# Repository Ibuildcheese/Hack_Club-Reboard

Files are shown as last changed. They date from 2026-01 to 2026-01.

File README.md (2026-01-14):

# The ReBoard
This is an 87 key custom ANSI mechanical keyboard with a Raspberry Pi Pico microcontroller using QMK Software to program the Pico. All keys in the firmware are 100% ANSI and I am using Cherry MX Blue switches.

### Why/how i made this
Firstly, i want to say that this will be the first PCB that i have ever made and it was all because i thought making a new keyboard would be easier than cleaning my old one. My dell keyboard, sk-8125, my dad bought before i was born, and it was discontinued 10 years ago, so i comitted myself to making a keyboard better than something from that time period by myself. Firstly, I looked up a bunch of tutorial videos but since they didn't help me at all i decided to just get started and go from there however, there was a lot of time in between from waiting on a friend to answer a question i had to having to completely scrapping my initial 100% keyboard i had in mind because of some fatal errors i made during the schematic. With the amount of issues and redos i encountered, i never would have thought i'd finish in time, let alone ~15 days before the deadline. Even though all this inexperience did come at a cost (i.e. spending 3 whole days to find a 3d-model of a cherry MX switch) i still cant thank Hack Club enough for giving me the opportunity to actually get started making amazing projects like these and being able to learn and problem solve along the way.

### Completion Chart

| Name | Status | Extra |
| :-: | :-: | :-: |
| PCB | Designed and order ready |  |
| PCB-Parts | Chosen, order ready |  |
| Case | Designed, not yet printed |  |
| Firmware | Configured, not yet tested on hardware |  |

___

## Screenshots of Design: 
| PCB - Front - Rendered | PCB - Back Rendered |
| :-: | :-: |
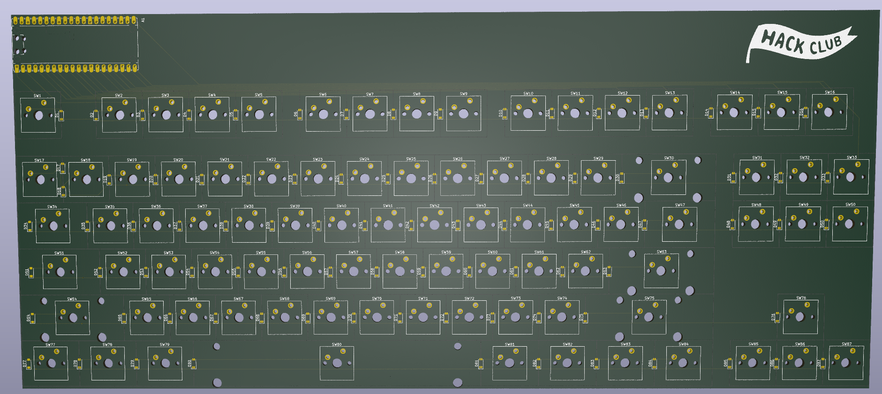
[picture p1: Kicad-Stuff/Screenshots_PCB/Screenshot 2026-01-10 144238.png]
PCB-Front-Rendered
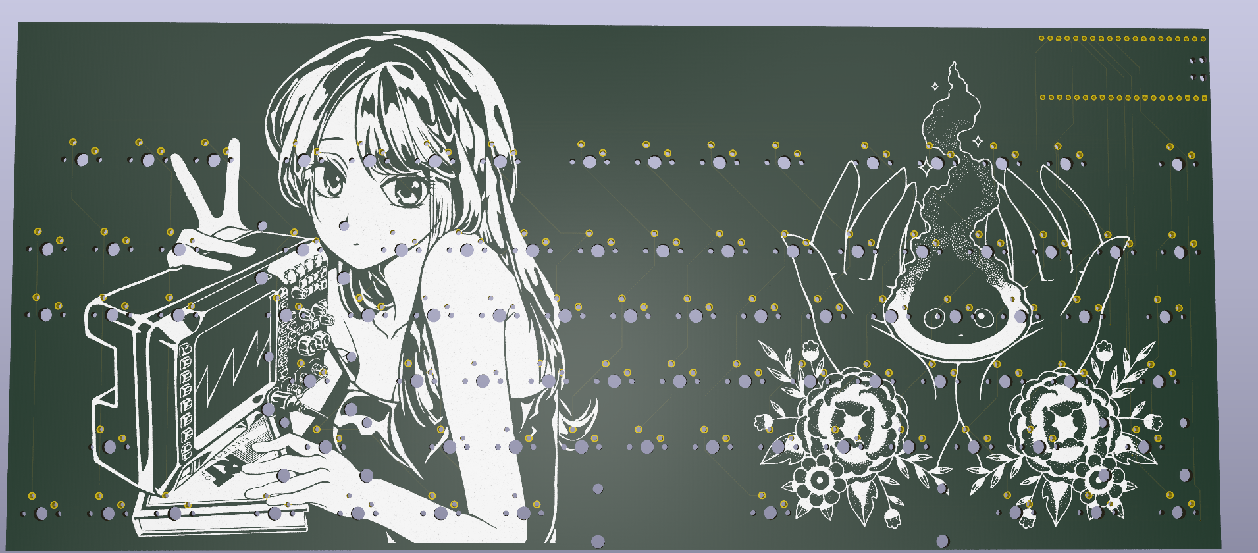
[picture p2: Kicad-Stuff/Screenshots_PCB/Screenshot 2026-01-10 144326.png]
PCB-Back-Rendered
|  |  |
| PCB - Editor - No-Silk | PCB - Editor - Silk |
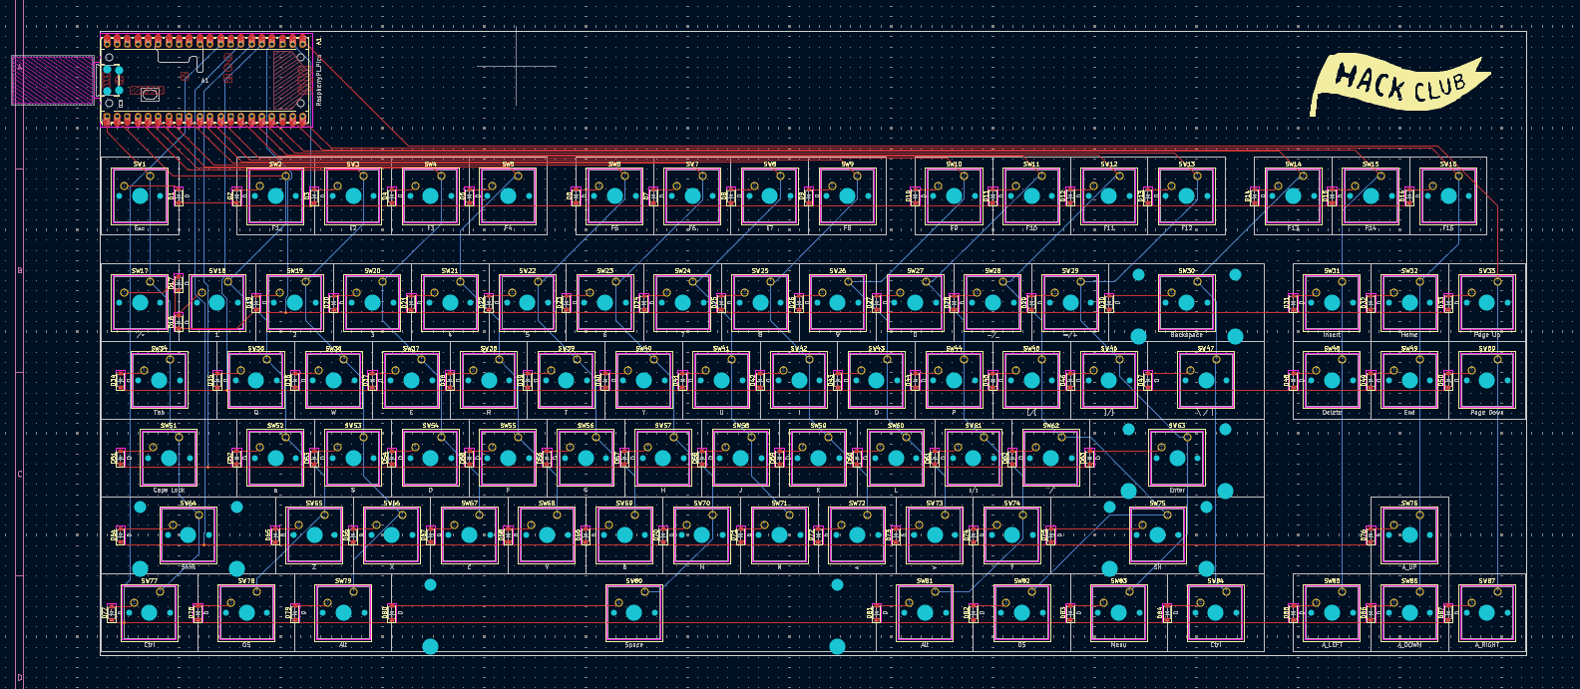
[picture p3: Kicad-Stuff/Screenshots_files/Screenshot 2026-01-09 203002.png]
PCB-Editor-No-Silk
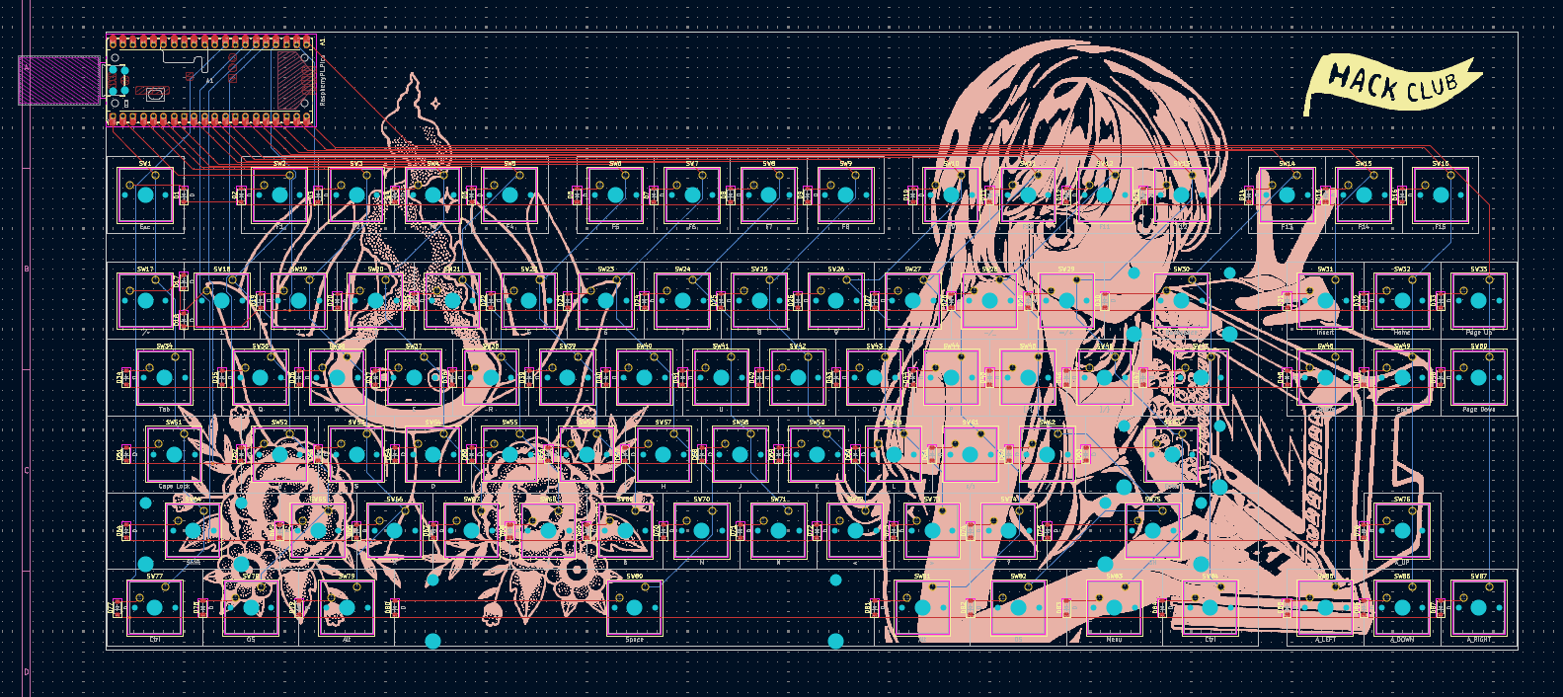
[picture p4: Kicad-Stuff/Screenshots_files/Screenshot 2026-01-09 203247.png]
PCB-Editor-Silk
|  |  |

| Schematic | 
| - |
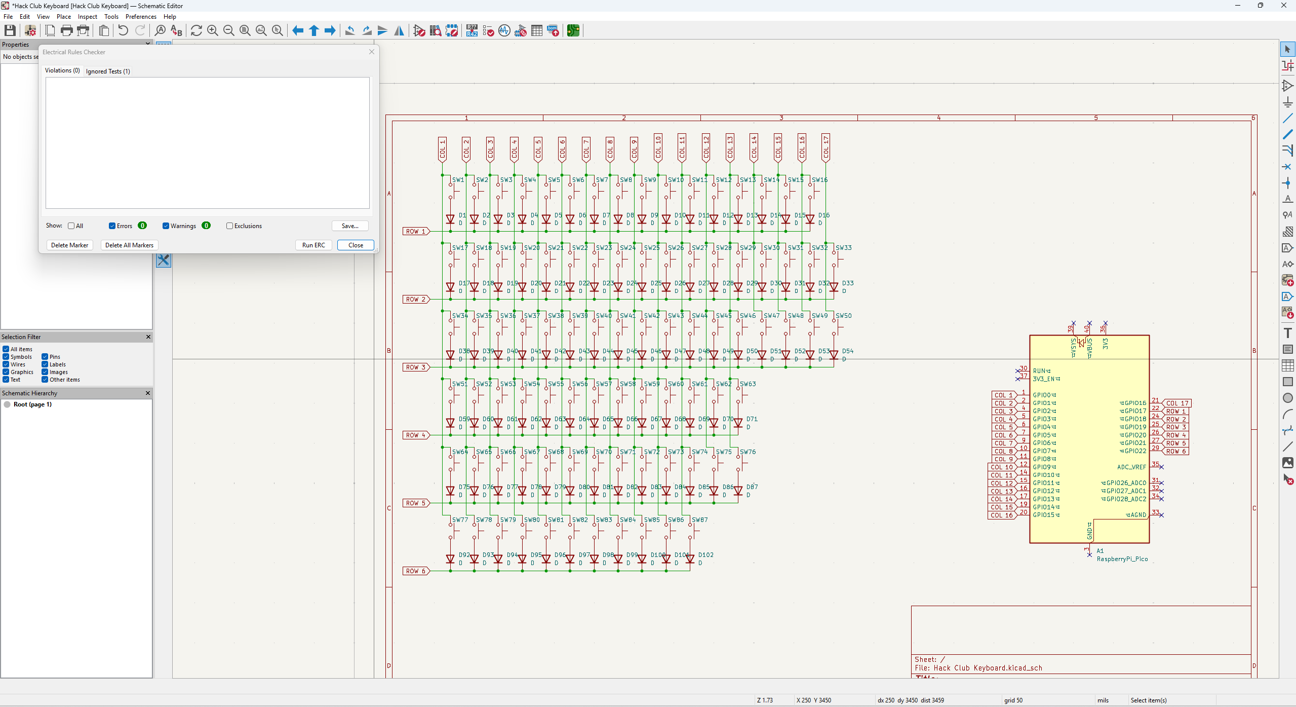
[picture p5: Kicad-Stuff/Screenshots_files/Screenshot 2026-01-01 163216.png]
Schematic-Img
|  |

| CAD - Render - Main |
| - |
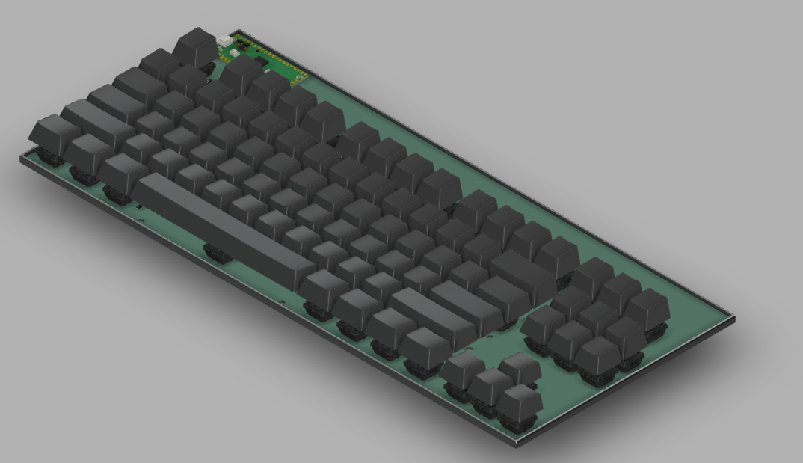
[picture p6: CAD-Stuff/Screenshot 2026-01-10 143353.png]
CAD-Render-Main
|  |

| CAD - Render - Top | Cad - Render - Bottom |
| - | - |
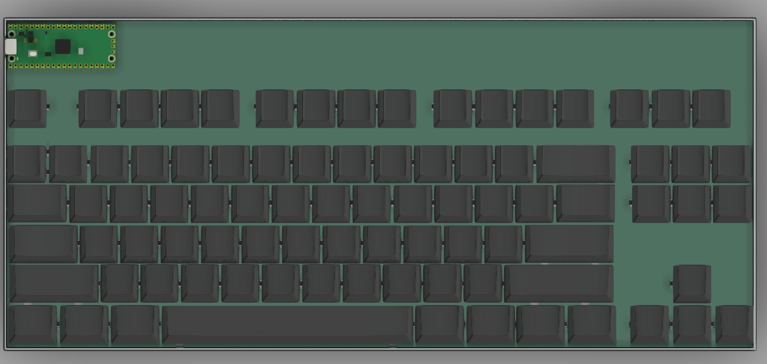
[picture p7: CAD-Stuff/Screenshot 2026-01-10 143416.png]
CAD-Render-Top
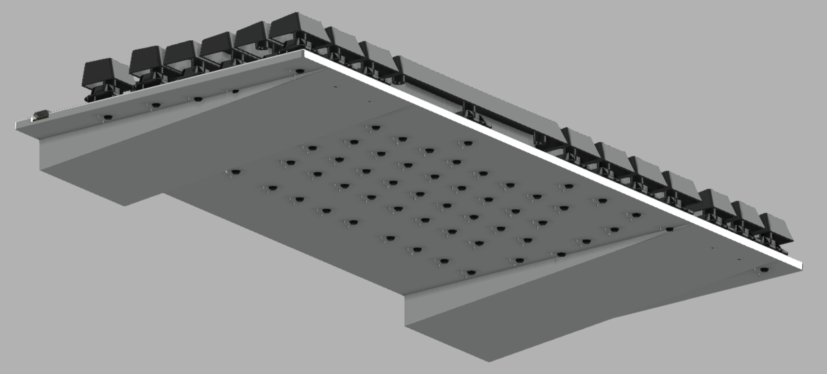
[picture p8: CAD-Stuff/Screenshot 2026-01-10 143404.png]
CAD-Render-Bottom
|  |  |

___

## BOM

| Amt | Name | Price | Link | Extra |
| - | - | - | - | - |
| x90 | Cherry MX Blue Switches | $34.50 | [Link](https://www.aliexpress.us/item/3256806124797516.html?) | Color: Blue, 90pcs |
| x98 | Cherry Profile Keycaps | $11.72 | [Link](https://www.aliexpress.us/item/3256808041449227.html?) | color: beige |
| x5 | Stabilizers | $0.99 | [Link](https://www.aliexpress.us/item/2251832533420646.html?) | 1x6.25 (6u or 7u) + 4x2u |
| x100 | Diodes | $1.30 | [Link](https://www.aliexpress.us/item/3256807350544438.html?) | 100pc option |
| 1x | PCB | $21.35 | [Link](https://jlcpcb.com) | --- |
| 1x | 3d Printed Case | --- | --- | I will print it myself |
| 1x | Raspberry Pi Pico | $3.75 | [Link](https://www.aliexpress.us/item/3256806652932348.html?) | --- |
| --- | Total | $73.61 | --- | --- |

| BOM - Screenshot - PCB |
| :-: |
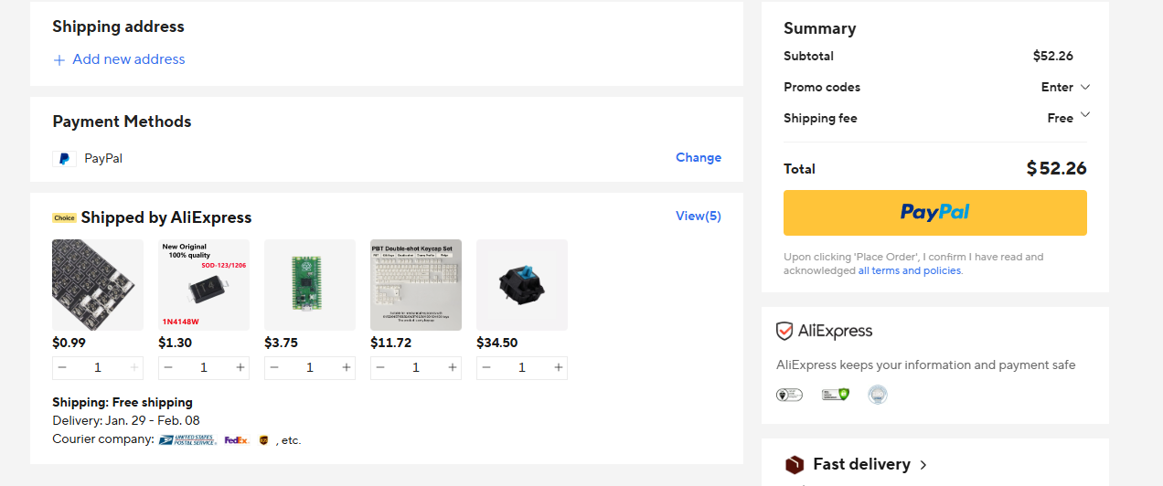
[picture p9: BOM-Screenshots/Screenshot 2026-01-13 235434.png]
PCB-BOM-SS
|  |
| BOM - Screenshot - AliExpress |
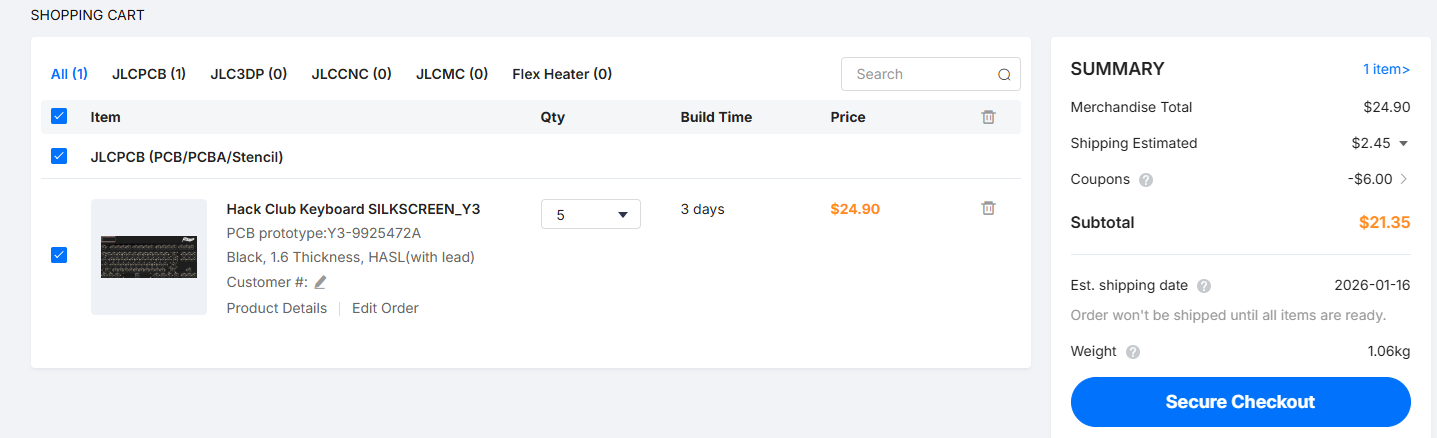
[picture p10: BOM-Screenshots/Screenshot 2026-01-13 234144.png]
AliExpress-BOM-SS
|  |

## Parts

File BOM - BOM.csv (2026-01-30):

Amount | Item | Price | Link | Misc.
x90 | Cherry MX Blue Switches | $34.50 | https://www.aliexpress.us/item/3256806124797516.html? | Color: Blue, 90pcs
x98 | Cherry Profile Keycaps | $11.72 | https://www.aliexpress.us/item/3256808041449227.html? | color: beige
x5 | Stabilizers | $0.99 | https://www.aliexpress.us/item/2251832533420646.html? | 1x6.25 (6u or 7u) + 4x2u
x100 | Diodes | $1.30 | https://www.aliexpress.us/item/3256807350544438.html? | 100pc option
x1 | PCB | $21.35 | https://jlcpcb.com
x1 | 3d Printed Case
x1 | Raspberry Pi Pico | $3.75 | https://www.aliexpress.us/item/3256806652932348.html? | I will print it myself
 | Total | $73.61

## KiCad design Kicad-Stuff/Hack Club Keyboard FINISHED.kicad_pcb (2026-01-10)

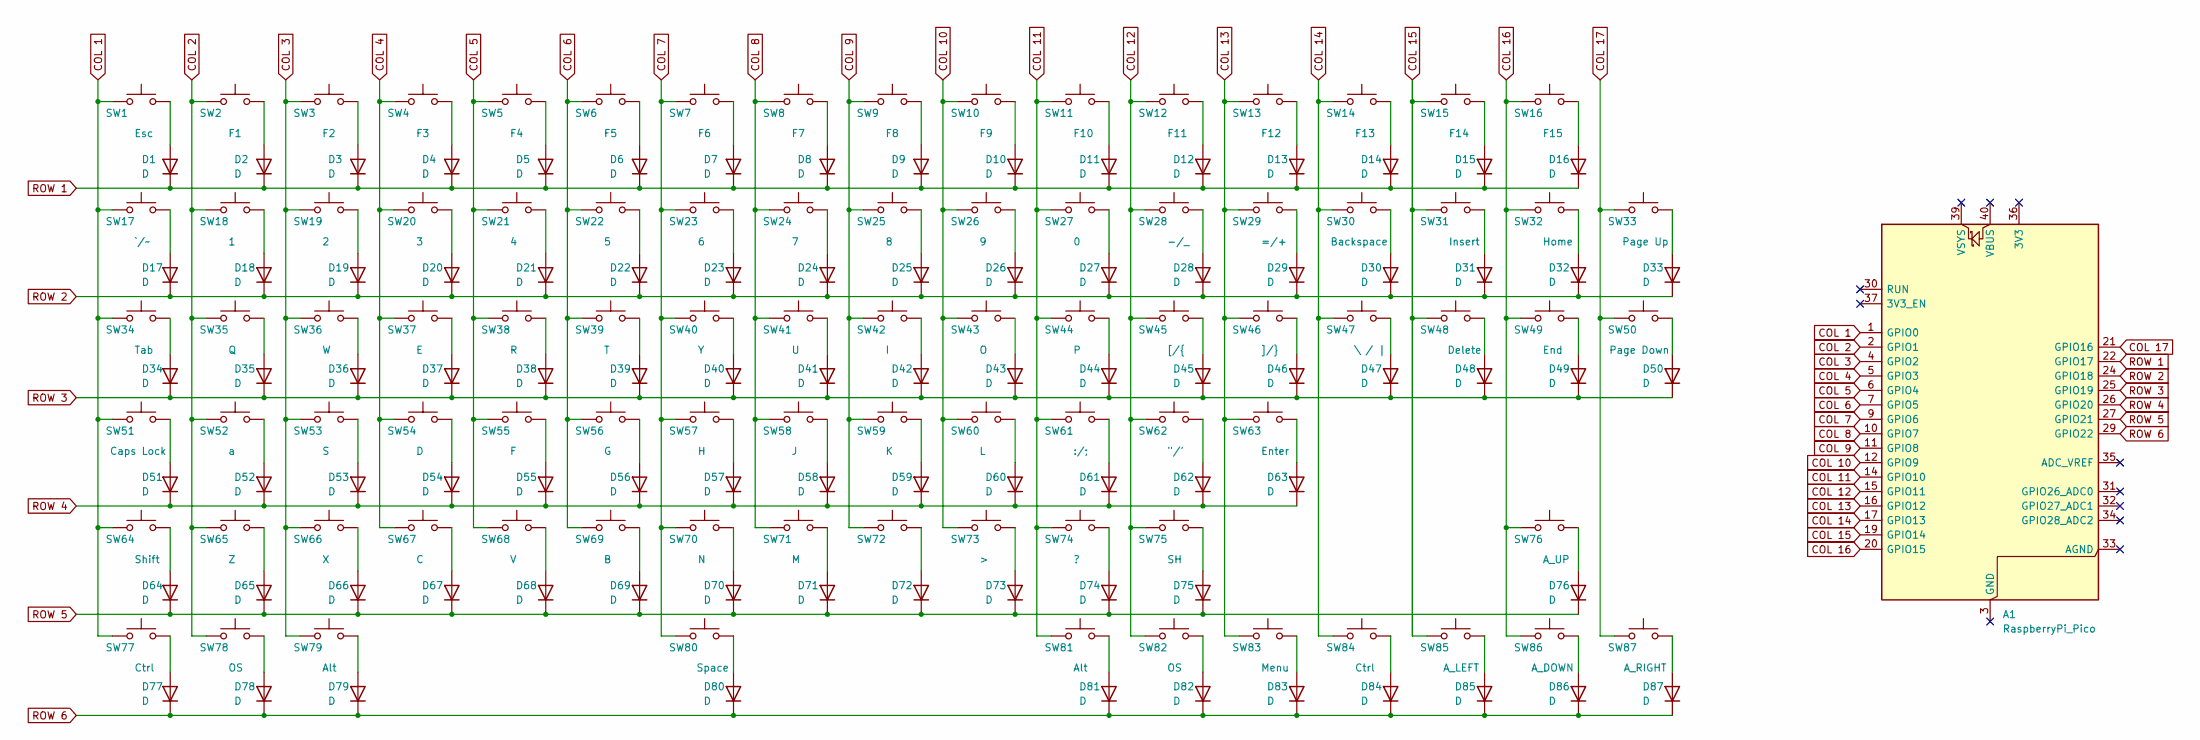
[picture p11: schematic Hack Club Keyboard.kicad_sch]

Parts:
A1: RaspberryPi_Pico; RaspberryPi_Pico_Common_Unspecified
D1, D2, D3, D4, D5, D6, D7, D8, D9, D10, D11, D12, D13, D14, D15, D16, D17, D18, D19, D20, D21, D22, D23, D24, D25, D26, D27, D28, D29, D30, D31, D32, D33, D34, D35, D36, D37, D38, D39, D40, D41, D42, D43, D44, D45, D46, D47, D48, D49, D50, D51, D52, D53, D54, D55, D56, D57, D58, D59, D60, D61, D62, D63, D64, D65, D66, D67, D68, D69, D70, D71, D72, D73, D74, D75, D76, D77, D78, D79, D80, D81, D82, D83, D84, D85, D86, D87: D; D_SOD-123
SW1: Esc; SW_Cherry_MX_1.00u_PCB
SW2: F1; SW_Cherry_MX_1.00u_PCB
SW3: F2; SW_Cherry_MX_1.00u_PCB
SW4: F3; SW_Cherry_MX_1.00u_PCB
SW5: F4; SW_Cherry_MX_1.00u_PCB
SW6: F5; SW_Cherry_MX_1.00u_PCB
SW7: F6; SW_Cherry_MX_1.00u_PCB
SW8: F7; SW_Cherry_MX_1.00u_PCB
SW9: F8; SW_Cherry_MX_1.00u_PCB
SW10: F9; SW_Cherry_MX_1.00u_PCB
SW11: F10; SW_Cherry_MX_1.00u_PCB
SW12: F11; SW_Cherry_MX_1.00u_PCB
SW13: F12; SW_Cherry_MX_1.00u_PCB
SW14: F13; SW_Cherry_MX_1.00u_PCB
SW15: F14; SW_Cherry_MX_1.00u_PCB
SW16: F15; SW_Cherry_MX_1.00u_PCB
SW17: `/~; SW_Cherry_MX_1.00u_PCB
SW18: 1; SW_Cherry_MX_1.00u_PCB
SW19: 2; SW_Cherry_MX_1.00u_PCB
SW20: 3; SW_Cherry_MX_1.00u_PCB
SW21: 4; SW_Cherry_MX_1.00u_PCB
SW22: 5; SW_Cherry_MX_1.00u_PCB
SW23: 6; SW_Cherry_MX_1.00u_PCB
SW24: 7; SW_Cherry_MX_1.00u_PCB
SW25: 8; SW_Cherry_MX_1.00u_PCB
SW26: 9; SW_Cherry_MX_1.00u_PCB
SW27: 0; SW_Cherry_MX_1.00u_PCB
SW28: -/_; SW_Cherry_MX_1.00u_PCB
SW29: =/+; SW_Cherry_MX_1.00u_PCB
SW30: Backspace; SW_Cherry_MX_2.00u_PCB
SW31: Insert; SW_Cherry_MX_1.00u_PCB
SW32: Home; SW_Cherry_MX_1.00u_PCB
SW33: Page Up; SW_Cherry_MX_1.00u_PCB
SW34: Tab; SW_Cherry_MX_1.50u_PCB
SW35: Q; SW_Cherry_MX_1.00u_PCB
SW36: W; SW_Cherry_MX_1.00u_PCB
SW37: E; SW_Cherry_MX_1.00u_PCB
SW38: R; SW_Cherry_MX_1.00u_PCB
SW39: T; SW_Cherry_MX_1.00u_PCB
SW40: Y; SW_Cherry_MX_1.00u_PCB
SW41: U; SW_Cherry_MX_1.00u_PCB
SW42: I; SW_Cherry_MX_1.00u_PCB
SW43: O; SW_Cherry_MX_1.00u_PCB
SW44: P; SW_Cherry_MX_1.00u_PCB
SW45: [/{; SW_Cherry_MX_1.00u_PCB
SW46: ]/}; SW_Cherry_MX_1.00u_PCB
SW47: \ / |; SW_Cherry_MX_1.50u_PCB
SW48: Delete; SW_Cherry_MX_1.00u_PCB
SW49: End; SW_Cherry_MX_1.00u_PCB
SW50: Page Down; SW_Cherry_MX_1.00u_PCB
SW51: Caps Lock; SW_Cherry_MX_1.75u_PCB
SW52: a; SW_Cherry_MX_1.00u_PCB
SW53: S; SW_Cherry_MX_1.00u_PCB
SW54: D; SW_Cherry_MX_1.00u_PCB
SW55: F; SW_Cherry_MX_1.00u_PCB
SW56: G; SW_Cherry_MX_1.00u_PCB
SW57: H; SW_Cherry_MX_1.00u_PCB
SW58: J; SW_Cherry_MX_1.00u_PCB
SW59: K; SW_Cherry_MX_1.00u_PCB
SW60: L; SW_Cherry_MX_1.00u_PCB
SW61: :/;; SW_Cherry_MX_1.00u_PCB
SW62: "/'; SW_Cherry_MX_1.00u_PCB
SW63: Enter; SW_Cherry_MX_2.25u_PCB
SW64: Shift; SW_Cherry_MX_2.25u_PCB
SW65: Z; SW_Cherry_MX_1.00u_PCB
SW66: X; SW_Cherry_MX_1.00u_PCB
SW67: C; SW_Cherry_MX_1.00u_PCB
SW68: V; SW_Cherry_MX_1.00u_PCB
SW69: B; SW_Cherry_MX_1.00u_PCB
SW70: N; SW_Cherry_MX_1.00u_PCB
SW71: M; SW_Cherry_MX_1.00u_PCB
SW72: SW_Cherry_MX_1.00u_PCB
SW73: >; SW_Cherry_MX_1.00u_PCB
SW74: ?; SW_Cherry_MX_1.00u_PCB
SW75: SH; SW_Cherry_MX_2.75u_PCB
SW76: A_UP; SW_Cherry_MX_1.00u_PCB
SW77, SW84: Ctrl; SW_Cherry_MX_1.25u_PCB
SW78, SW82: OS; SW_Cherry_MX_1.25u_PCB
SW79, SW81: Alt; SW_Cherry_MX_1.25u_PCB
SW80: Space; SW_Cherry_MX_6.25u_PCB
SW83: Menu; SW_Cherry_MX_1.25u_PCB
SW85: A_LEFT; SW_Cherry_MX_1.00u_PCB
SW86: A_DOWN; SW_Cherry_MX_1.00u_PCB
SW87: A_RIGHT; SW_Cherry_MX_1.00u_PCB

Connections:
COL 1: A1.1 (GPIO0), SW1.1, SW17.1, SW34.1, SW51.1, SW64.1, SW77.1
COL 2: A1.2 (GPIO1), SW2.1, SW18.1, SW35.1, SW52.1, SW65.1, SW78.1
COL 3: A1.4 (GPIO2), SW3.1, SW19.1, SW36.1, SW53.1, SW66.1, SW79.1
COL 4: A1.5 (GPIO3), SW4.1, SW20.1, SW37.1, SW54.1, SW67.1
COL 5: A1.6 (GPIO4), SW5.1, SW21.1, SW38.1, SW55.1, SW68.1
COL 6: A1.7 (GPIO5), SW6.1, SW22.1, SW39.1, SW56.1, SW69.1
COL 7: A1.9 (GPIO6), SW7.1, SW23.1, SW40.1, SW57.1, SW70.1, SW80.1
COL 8: A1.10 (GPIO7), SW8.1, SW24.1, SW41.1, SW58.1, SW71.1
COL 9: A1.11 (GPIO8), SW9.1, SW25.1, SW42.1, SW59.1, SW72.1
COL 10: A1.12 (GPIO9), SW10.1, SW26.1, SW43.1, SW60.1, SW73.1
COL 11: A1.14 (GPIO10), SW11.1, SW27.1, SW44.1, SW61.1, SW74.1, SW81.1
COL 12: A1.15 (GPIO11), SW12.1, SW28.1, SW45.1, SW62.1, SW75.1, SW82.1
COL 13: A1.16 (GPIO12), SW13.1, SW29.1, SW46.1, SW63.1, SW83.1
COL 14: A1.17 (GPIO13), SW14.1, SW30.1, SW47.1, SW84.1
COL 15: A1.19 (GPIO14), SW15.1, SW31.1, SW48.1, SW85.1
COL 16: A1.20 (GPIO15), SW16.1, SW32.1, SW49.1, SW76.1, SW86.1
COL 17: A1.21 (GPIO16), SW33.1, SW50.1, SW87.1
unnamed: D1.2 (A), SW1.2
unnamed: D2.2 (A), SW2.2
unnamed: D3.2 (A), SW3.2
unnamed: D4.2 (A), SW4.2
unnamed: D5.2 (A), SW5.2
unnamed: D6.2 (A), SW6.2
unnamed: D7.2 (A), SW7.2
unnamed: D8.2 (A), SW8.2
unnamed: D9.2 (A), SW9.2
unnamed: D10.2 (A), SW10.2
unnamed: D11.2 (A), SW11.2
unnamed: D12.2 (A), SW12.2
unnamed: D13.2 (A), SW13.2
unnamed: D14.2 (A), SW14.2
unnamed: D15.2 (A), SW15.2
unnamed: D16.2 (A), SW16.2
unnamed: D17.2 (A), SW17.2
unnamed: D18.2 (A), SW18.2
unnamed: D19.2 (A), SW19.2
unnamed: D20.2 (A), SW20.2
unnamed: D21.2 (A), SW21.2
unnamed: D22.2 (A), SW22.2
unnamed: D23.2 (A), SW23.2
unnamed: D24.2 (A), SW24.2
unnamed: D25.2 (A), SW25.2
unnamed: D26.2 (A), SW26.2
unnamed: D27.2 (A), SW27.2
unnamed: D28.2 (A), SW28.2
unnamed: D29.2 (A), SW29.2
unnamed: D30.2 (A), SW30.2
unnamed: D31.2 (A), SW31.2
unnamed: D32.2 (A), SW32.2
unnamed: D33.2 (A), SW33.2
unnamed: D34.2 (A), SW34.2
unnamed: D35.2 (A), SW35.2
unnamed: D36.2 (A), SW36.2
unnamed: D37.2 (A), SW37.2
unnamed: D38.2 (A), SW38.2
unnamed: D39.2 (A), SW39.2
unnamed: D40.2 (A), SW40.2
unnamed: D41.2 (A), SW41.2
unnamed: D42.2 (A), SW42.2
unnamed: D43.2 (A), SW43.2
unnamed: D44.2 (A), SW44.2
unnamed: D45.2 (A), SW45.2
unnamed: D46.2 (A), SW46.2
unnamed: D47.2 (A), SW47.2
unnamed: D48.2 (A), SW48.2
unnamed: D49.2 (A), SW49.2
unnamed: D50.2 (A), SW50.2
unnamed: D51.2 (A), SW51.2
unnamed: D52.2 (A), SW52.2
unnamed: D53.2 (A), SW53.2
unnamed: D54.2 (A), SW54.2
unnamed: D55.2 (A), SW55.2
unnamed: D56.2 (A), SW56.2
unnamed: D57.2 (A), SW57.2
unnamed: D58.2 (A), SW58.2
unnamed: D59.2 (A), SW59.2
unnamed: D60.2 (A), SW60.2
unnamed: D61.2 (A), SW61.2
unnamed: D62.2 (A), SW62.2
unnamed: D63.2 (A), SW63.2
unnamed: D64.2 (A), SW64.2
unnamed: D65.2 (A), SW65.2
unnamed: D66.2 (A), SW66.2
unnamed: D67.2 (A), SW67.2
unnamed: D68.2 (A), SW68.2
unnamed: D69.2 (A), SW69.2
unnamed: D70.2 (A), SW70.2
unnamed: D71.2 (A), SW71.2
unnamed: D72.2 (A), SW72.2
unnamed: D73.2 (A), SW73.2
unnamed: D74.2 (A), SW74.2
unnamed: D75.2 (A), SW75.2
unnamed: D76.2 (A), SW76.2
unnamed: D77.2 (A), SW77.2
unnamed: D78.2 (A), SW78.2
unnamed: D79.2 (A), SW79.2
unnamed: D80.2 (A), SW80.2
unnamed: D81.2 (A), SW81.2
unnamed: D82.2 (A), SW82.2
unnamed: D83.2 (A), SW83.2
unnamed: D84.2 (A), SW84.2
unnamed: D85.2 (A), SW85.2
unnamed: D86.2 (A), SW86.2
unnamed: D87.2 (A), SW87.2
ROW 1: A1.22 (GPIO17), D1.1 (K), D2.1 (K), D3.1 (K), D4.1 (K), D5.1 (K), D6.1 (K), D7.1 (K), D8.1 (K), D9.1 (K), D10.1 (K), D11.1 (K), D12.1 (K), D13.1 (K), D14.1 (K), D15.1 (K), D16.1 (K)
ROW 2: A1.24 (GPIO18), D17.1 (K), D18.1 (K), D19.1 (K), D20.1 (K), D21.1 (K), D22.1 (K), D23.1 (K), D24.1 (K), D25.1 (K), D26.1 (K), D27.1 (K), D28.1 (K), D29.1 (K), D30.1 (K), D31.1 (K), D32.1 (K), D33.1 (K)
ROW 3: A1.25 (GPIO19), D34.1 (K), D35.1 (K), D36.1 (K), D37.1 (K), D38.1 (K), D39.1 (K), D40.1 (K), D41.1 (K), D42.1 (K), D43.1 (K), D44.1 (K), D45.1 (K), D46.1 (K), D47.1 (K), D48.1 (K), D49.1 (K), D50.1 (K)
ROW 4: A1.26 (GPIO20), D51.1 (K), D52.1 (K), D53.1 (K), D54.1 (K), D55.1 (K), D56.1 (K), D57.1 (K), D58.1 (K), D59.1 (K), D60.1 (K), D61.1 (K), D62.1 (K), D63.1 (K)
ROW 5: A1.27 (GPIO21), D64.1 (K), D65.1 (K), D66.1 (K), D67.1 (K), D68.1 (K), D69.1 (K), D70.1 (K), D71.1 (K), D72.1 (K), D73.1 (K), D74.1 (K), D75.1 (K), D76.1 (K)
ROW 6: A1.29 (GPIO22), D77.1 (K), D78.1 (K), D79.1 (K), D80.1 (K), D81.1 (K), D82.1 (K), D83.1 (K), D84.1 (K), D85.1 (K), D86.1 (K), D87.1 (K)

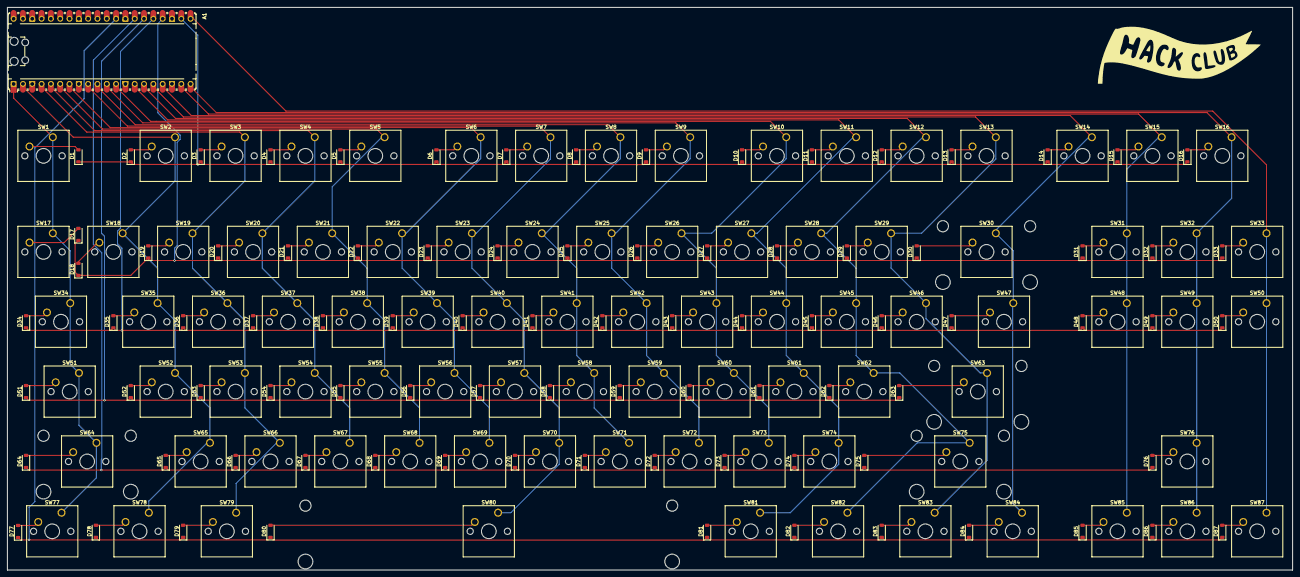
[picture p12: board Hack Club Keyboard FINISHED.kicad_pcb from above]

Board: 2 copper layers, 350.5 x 153.4 mm, 175 parts (0 on the bottom side), 110 nets.

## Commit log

2026-01-05 Create Kicad Stuff
2026-01-05 add Kicad Files
    [Hack Club Keyboard FINISHED.kicad_pcb, Hack Club Keyboard.kicad_sch]
2026-01-14 Update README.md - BOM
